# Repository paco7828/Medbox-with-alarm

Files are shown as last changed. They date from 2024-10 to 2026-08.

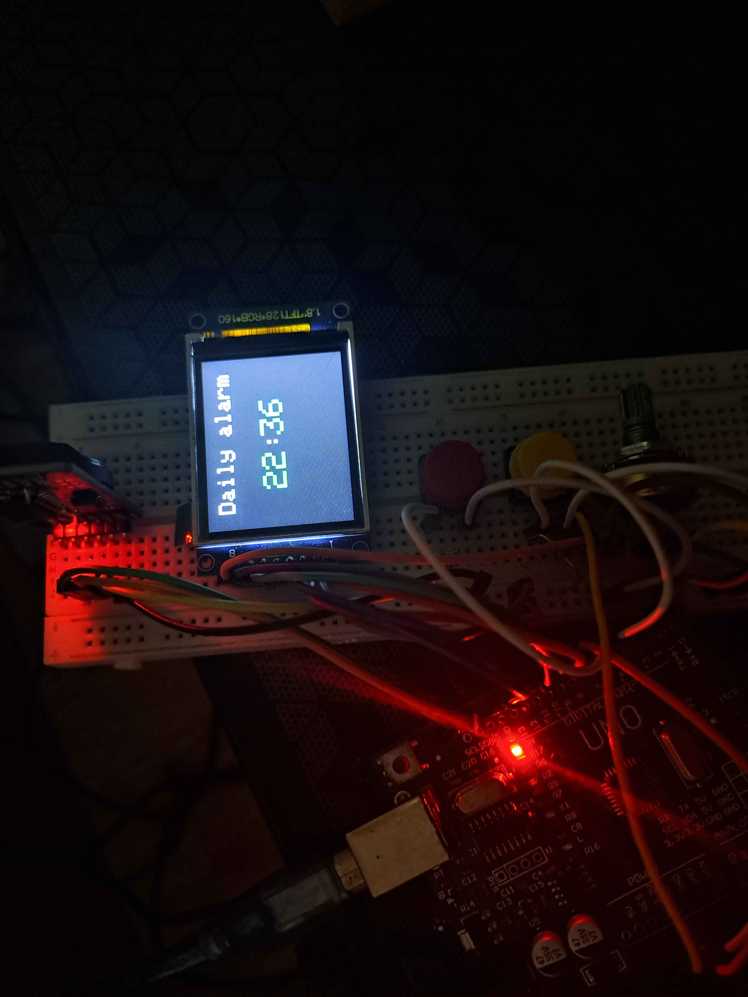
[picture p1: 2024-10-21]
models/proto-1.jpg

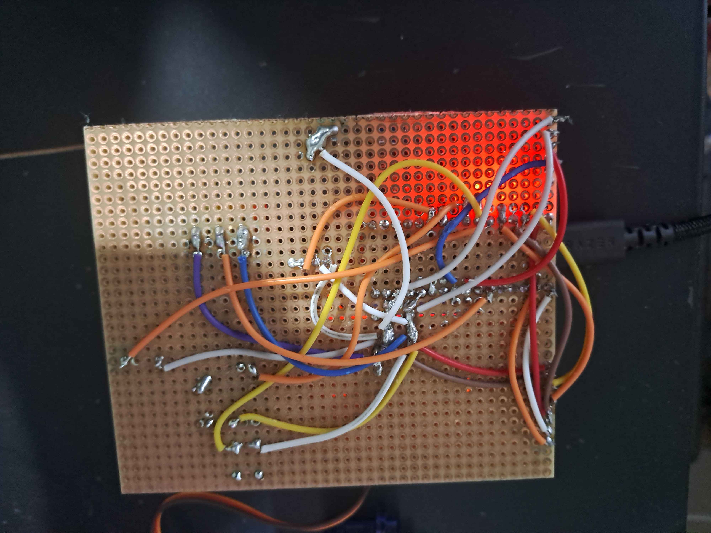
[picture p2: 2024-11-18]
models/v1-final-back.jpg

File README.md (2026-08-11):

# Timed Box

Battery-powered time-locked box driven by an ESP32-C3 Supermini. It functions as an interactive alarm clock that uses a servo motor to automatically open at a specific time. It utilizes deep sleep mode to preserve battery life when not actively in use.

## Features

- **Time-Triggered Lockbox:** Automatically triggers a servo to open the box when the programmed alarm goes off. The box automatically closes after 30 seconds.
- **Ultra-Low Power Mode:** Enters deep sleep after 60 seconds of inactivity. Automatically wakes up exactly when the alarm is due or via a manual button press.
- **1.8" TFT Display:** Shows real-time clock, date, day of the week, and current alarm status with optimized rendering.
- **Precision Timekeeping:** Uses a DS3231M RTC circuit to maintain accurate time independently of the MCU.
- **Audio Feedback:** Integrated buzzer plays alarm sequences and button interaction sounds.
- **Manual Override:** Long-pressing the main button allows you to manually open or close the box at any time without an alarm.
- **On-Device Configuration:** Two physical buttons to toggle the alarm state, configure the alarm time, and wake the device from sleep. Alarm times are saved in non-volatile memory.
- **Integrated Power Management:** Runs on a 3.7V LiPo battery. Includes a built-in USB-C charging circuit with battery protection and a boost converter for 5V components.

## Hardware Components

- **MCU:** ESP32-C3 SUPERMINI
- **RTC:** DS3231M
- **Display:** 1.8" TFT Screen (ST7735)
- **Actuator:** Servo Motor
- **Audio:** Active Buzzer
- **Power System:** 3.7V LiPo Battery, TP4056 Battery Charger / Protection module (with 8205A & DW01A), MT3608 Step-up Converter (3.7V -> 5V)
- **Inputs:** 2x Tactile Push Buttons, Power Switch

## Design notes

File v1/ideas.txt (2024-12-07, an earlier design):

Ideas:
-add different alarm sounds (functions) --> user can preview them and set an alarm sound
-attach servo to the circuit (small box which can be opened via servo) --> store medicine inside box
-attach water dispenser
	=> full medicine reminder kit (medicine alarm + box + water dispenser)
-add switch which acts as a screen on/off

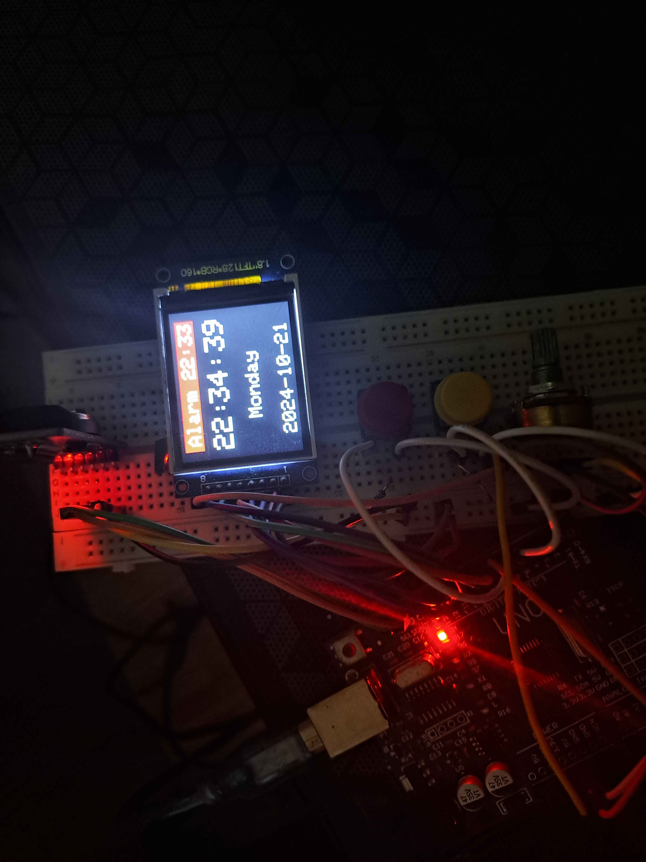
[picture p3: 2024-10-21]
models/proto-2.jpg

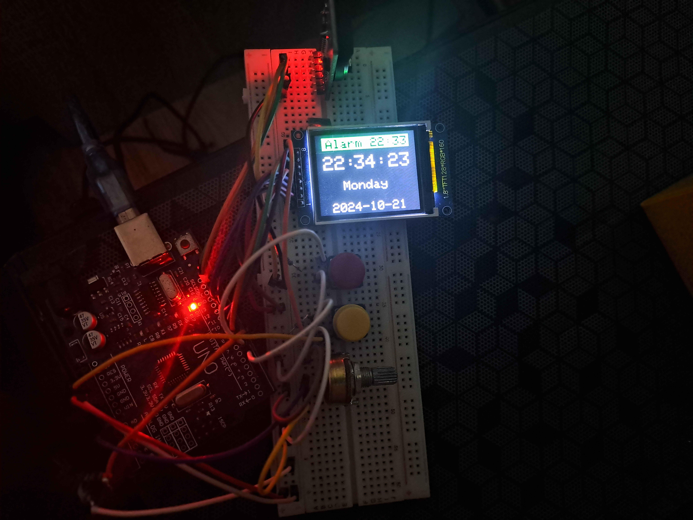
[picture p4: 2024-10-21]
models/proto-3.jpg

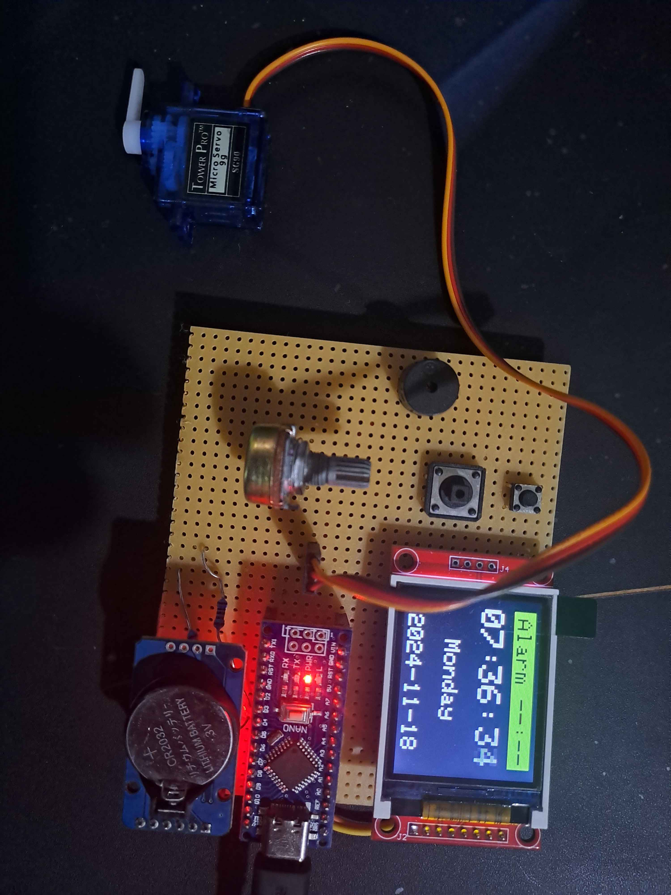
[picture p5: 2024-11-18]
models/v1-final-front.jpg

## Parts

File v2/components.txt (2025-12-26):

1x TYPE-C USB - https://www.hestore.hu/prod_10046971.html
2x 5.1k 0805 resistor - https://www.hestore.hu/prod_10001349.html
2x 1N5819 diode - https://www.hestore.hu/prod_10046229.html
1x Red LED - https://www.hestore.hu/prod_10043215.html
1x Green LED - https://www.hestore.hu/prod_10036384.html
3x 10uF 0805 capacitor - https://www.hestore.hu/prod_10032047.html
3x 1k 0805 resistor - https://www.hestore.hu/prod_10031299.html
1x TP4056 IC - https://www.hestore.hu/prod_10037291.html
1x 1.2k 0805 resistor - https://www.hestore.hu/prod_10001268.html
1x DW01 IC - https://www.hestore.hu/prod_10046612.html
1x 8205A IC - https://www.hestore.hu/prod_10045032.html
1x MT3608 IC - https://www.hestore.hu/prod_10048950.html
1x 22uH 0705 inductor - https://www.hestore.hu/prod_10046500.html
1x 7.5k 0805 resistor - https://www.hestore.hu/prod_10001197.html
1x B2B-XH-A - https://www.hestore.hu/prod_10041549.html
1x Buzzer - https://www.hestore.hu/prod_10044010.html
1x Power switch
1x B8B-XH-A - https://www.hestore.hu/prod_10041554.html
1x 1.8" TFT Display - https://www.hestore.hu/prod_10045986.html
1x 180° servo - https://www.hestore.hu/prod_10047934.html
1x MCU - https://www.hestore.hu/prod_10048018.html
2x 100nF 0805 capacitor - https://www.hestore.hu/prod_10001122.html
2x Button - https://www.hestore.hu/prod_10043772.html
1x DS3231M IC - https://www.aliexpress.com/item/1005008686698228.html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
2x 4.7k 0805 resistor - https://www.hestore.hu/prod_10001183.html
1x CR2032 Battery - https://www.hestore.hu/prod_10001070.html

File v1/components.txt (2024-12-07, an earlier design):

JC1216S18N (screen) --> https://www.hestore.hu/prod_10045986.html#
DS3231+AT24C32 RTCM (Real Time Clock module) --> https://www.hestore.hu/prod_10038042.html
LD-BZEN-1205 (buzzer) --> https://www.hestore.hu/prod_10040906.html
2x TACTS-12x12x7.3 (tact button) --> https://www.hestore.hu/prod_10042024.html
POM1615 LIN 10K B (potmeter) --> https://www.hestore.hu/prod_10027737.html
2x 10K 1% (pulldown resistor) --> https://www.hestore.hu/prod_10020541.html
AR-NANOCH-TYPE-C (microcontroller) --> https://www.hestore.hu/prod_10044468.html
MS/SG-90 servo (servo motor) --> https://www.hestore.hu/prod_10031188.html
TSM102A2 (toggle switch) --> https://www.hestore.hu/prod_10034537.html

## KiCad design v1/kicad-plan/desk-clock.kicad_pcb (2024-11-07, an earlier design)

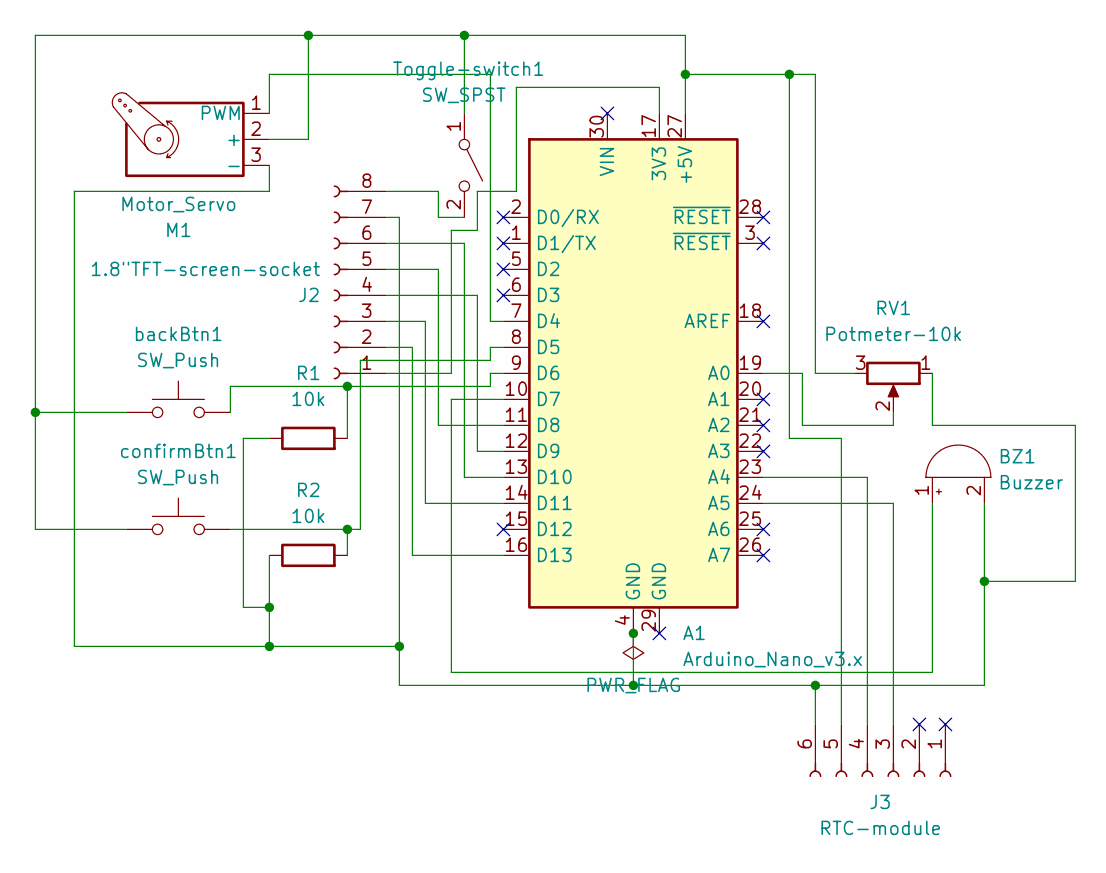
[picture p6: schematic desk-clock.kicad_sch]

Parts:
A1: Arduino_Nano_v3.x; Arduino_Nano
BZ1: Buzzer; Buzzer_TDK_PS1240P02BT_D12.2mm_H6.5mm
J2: 1.8"TFT-screen-socket; PinSocket_1x08_P2.54mm_Vertical
J3: RTC-module; PinSocket_1x06_P2.54mm_Vertical
M1: Motor_Servo; PinHeader_1x03_P2.54mm_Vertical
R1, R2: 10k; R_Axial_DIN0207_L6.3mm_D2.5mm_P10.16mm_Horizontal
RV1: Potmeter-10k; Potentiometer_Piher_PC-16_Single_Vertical
Toggle-switch1: SW_SPST; PinSocket_1x03_P2.54mm_Vertical
backBtn1: SW_Push; SW_Push_2P1T_Toggle_CK_PVA1xxH1xxxxxxV2
confirmBtn1: SW_Push; SW_Push_2P1T_Toggle_CK_PVA1xxH1xxxxxxV2

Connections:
unnamed: A1.17 (3V3), J2.1
unnamed: A1.27 (+5V), J3.5, M1.2 (+), RV1.3, Toggle-switch1.1 (A), backBtn1.1, confirmBtn1.1
unnamed: A1.19 (A0), RV1.2
unnamed: A1.23 (A4), J3.4
unnamed: A1.24 (A5), J3.3
unnamed: A1.7 (D4), M1.1 (PWM)
unnamed: A1.8 (D5), R2.2, confirmBtn1.2
unnamed: A1.9 (D6), R1.2, backBtn1.2
unnamed: A1.10 (D7), BZ1.1 (+)
unnamed: A1.11 (D8), J2.5
unnamed: A1.12 (D9), J2.4
unnamed: A1.13 (D10), J2.6
unnamed: A1.14 (D11), J2.3
unnamed: A1.16 (D13), J2.2
unnamed: A1.4 (GND), BZ1.2 (-), J2.7, J3.6, M1.3 (-), R1.1, R2.1, RV1.1
unnamed: J2.8, Toggle-switch1.2 (B)

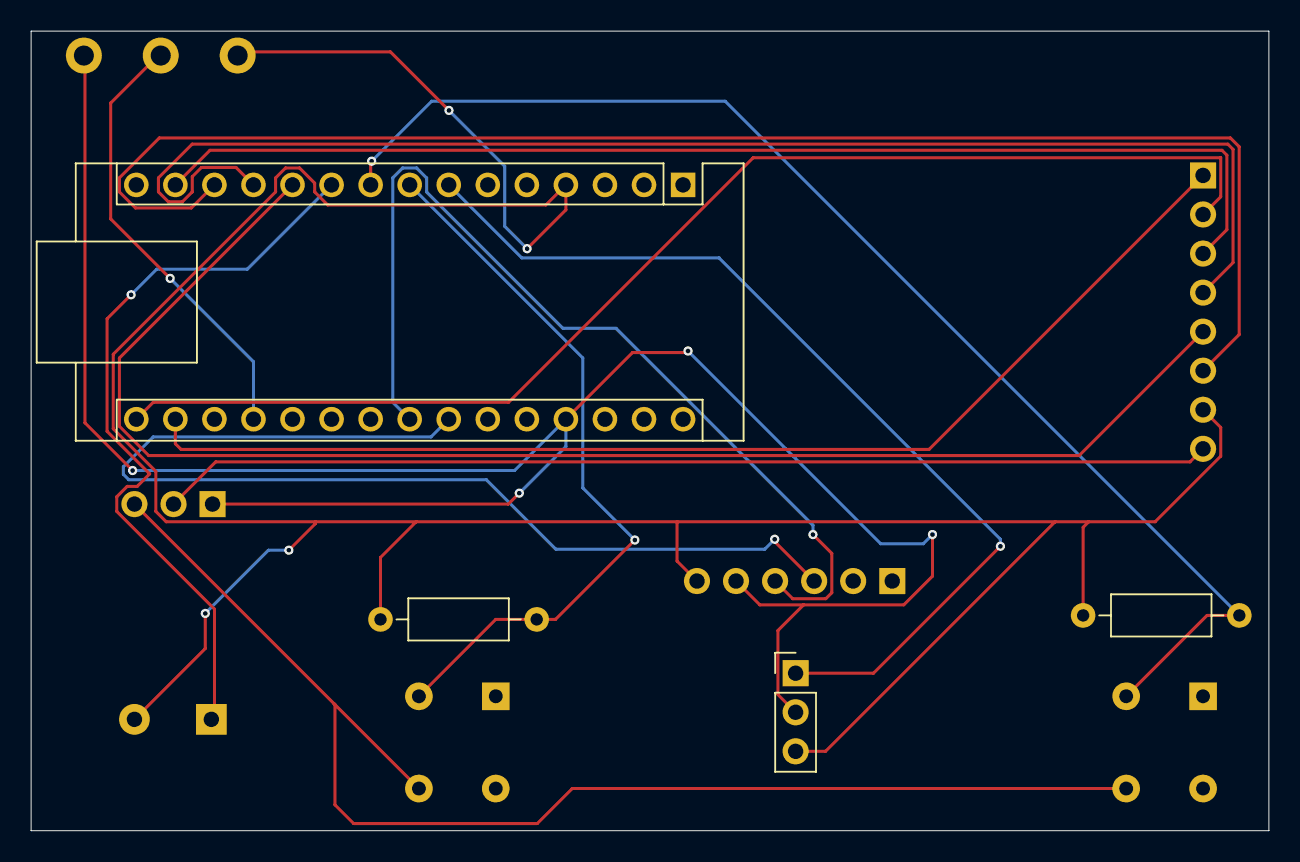
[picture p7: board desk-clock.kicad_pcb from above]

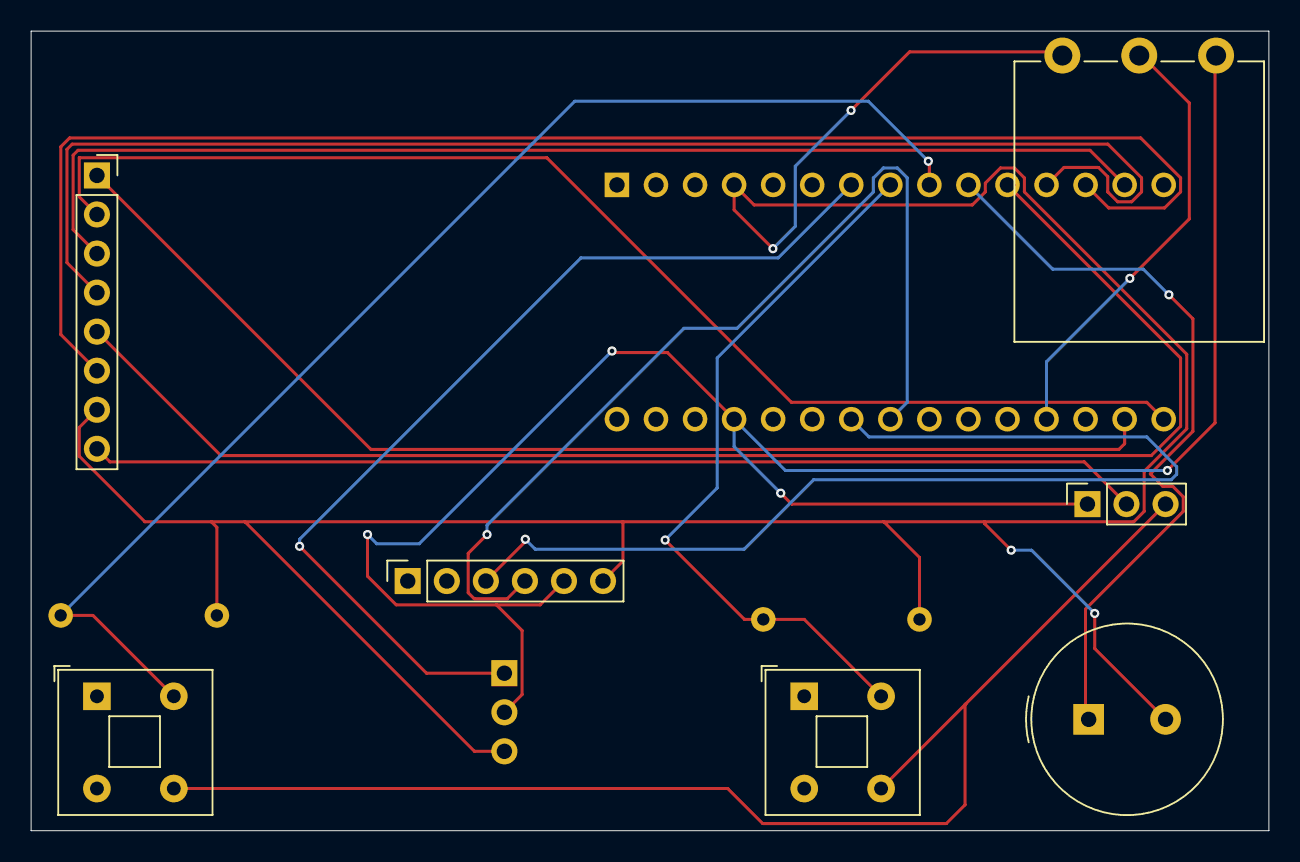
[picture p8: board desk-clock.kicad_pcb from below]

Board: 2 copper layers, 80.5 x 52.0 mm, 11 parts (7 on the bottom side), 16 nets.

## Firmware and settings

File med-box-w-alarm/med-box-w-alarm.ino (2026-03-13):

#include <Wire.h>
#include <RTClib.h>
#include <Adafruit_GFX.h>
#include <Adafruit_ST7735.h>
#include <Preferences.h>
#include <ESP32Servo.h>

// Pins
constexpr uint8_t TFT_CS = 9;
constexpr uint8_t TFT_DC = 5;
constexpr uint8_t TFT_RST = 8;
constexpr uint8_t TFT_MOSI = 4;
constexpr uint8_t TFT_SCK = 2;
constexpr uint8_t TFT_LED = 3;
constexpr uint8_t SERVO_PIN = 0;
constexpr uint8_t BTN1_PIN = 1;
constexpr uint8_t BTN2_PIN = 10;
constexpr uint8_t BUZZER_PIN = 20;
constexpr uint8_t RTC_SDA = 6;
constexpr uint8_t RTC_SCL = 7;

// Deep sleep
constexpr uint32_t AWAKE_TIME_MS = 60000;         // 1 minute (ms)
constexpr uint32_t MIN_SLEEP_TIME_US = 30000000;  // 30 seconds (µs)
unsigned long wakeTime = 0;

// Wakeup reason tracking - preserved across deep sleep
RTC_DATA_ATTR int lastAlarmHour = -1;
RTC_DATA_ATTR int lastAlarmMinute = -1;

// Instances
Servo boxServo;
RTC_DS3231 rtc;
Adafruit_ST7735 tft = Adafruit_ST7735(TFT_CS, TFT_DC, TFT_MOSI, TFT_SCK, TFT_RST);
Preferences preferences;

// RTC status
bool rtcFound = false;

// Helper variables
constexpr uint8_t BOX_OPEN_FOR = 30;  // seconds
bool alarmSet = true;
bool onMainScreen = true;
bool isHourSelected = true;
bool alarmActive = false;
bool boxOpen = false;
bool alarmStoppedForCurrentTime = false;
unsigned long boxOpenStartTime = 0;

// Button state variables
bool btn1LastReading = HIGH;
bool btn2LastReading = HIGH;
unsigned long btn1LastDebounceTime = 0;
unsigned long btn2LastDebounceTime = 0;
bool btn1State = HIGH;
bool btn2State = HIGH;
bool btn1LastStableState = HIGH;
bool btn2LastStableState = HIGH;

// BTN1 hold detection
const unsigned long HOLD_THRESHOLD_MS = 3000;  // 3 seconds to trigger hold
unsigned long btn1PressStartTime = 0;
bool btn1IsPhysicallyHeld = false;
bool btn1HoldActionFired = false;
bool manualBoxOpen = false;  // Box opened manually (separate from alarm)

// Button timing constants
const unsigned long doubleClickDelay = 400;
const unsigned long debounceDelay = 50;
unsigned long btn2FirstClick = 0;

// Alarm sound control
unsigned long lastBeepCycle = 0;
int beepState = 0;
bool alarmSoundActive = false;

// Alarm values
int alarmHourInt = 0;
int alarmMinuteInt = 0;

// Temporary alarm setting variables
int tempAlarmHour = 0;
int tempAlarmMinute = 0;

// Time display positioning and optimization
const int TIME_Y = 45;
const int TIME_SIZE = 3;

// Previous time values for optimization
int prevHourTens = -1;
int prevHourOnes = -1;
int prevMinTens = -1;
int prevMinOnes = -1;
int prevSecTens = -1;
int prevSecOnes = -1;

void setup() {
  wakeTime = millis();

  // Check wakeup reason FIRST
  esp_sleep_wakeup_cause_t wakeup_reason = esp_sleep_get_wakeup_cause();
  bool isGpioWakeup = (wakeup_reason == ESP_SLEEP_WAKEUP_GPIO);
  bool isFirstBoot = (wakeup_reason == ESP_SLEEP_WAKEUP_UNDEFINED);
  bool isTimerWakeup = (wakeup_reason == ESP_SLEEP_WAKEUP_TIMER);

  // Initialize Preferences
  preferences.begin("alarm-clock", false);

  // Load saved alarm values
  alarmHourInt = preferences.getInt("alarmHour", 0);
  alarmMinuteInt = preferences.getInt("alarmMin", 0);
  alarmSet = preferences.getBool("alarmSet", true);

  // Set up TFT backlight
  pinMode(TFT_LED, OUTPUT);
  digitalWrite(TFT_LED, HIGH);

  // Set up screen
  tft.initR(INITR_BLACKTAB);
  tft.fillScreen(ST77XX_BLACK);
  tft.setRotation(3);

  // Set up RTC with custom I2C pins
  Wire.begin(RTC_SDA, RTC_SCL);
  if (!rtc.begin()) {
    rtcFound = false;
  } else {
    rtcFound = true;

    // Check if time was already set manually
    bool timeWasSet = preferences.getBool("timeSet", false);

    if (!timeWasSet) {
      // MANUALLY SET THE TIME HERE ONLY ONCE!
      // Format: DateTime(year, month, day, hour, minute, second)
      rtc.adjust(DateTime(2025, 1, 30, 15, 33, 27));

      // Save flag so it doesn't reset again
      preferences.putBool("timeSet", true);
    }
  }

  // Set pins
  pinMode(BUZZER_PIN, OUTPUT);
  pinMode(BTN1_PIN, INPUT_PULLUP);
  pinMode(BTN2_PIN, INPUT_PULLUP);

  boxServo.attach(SERVO_PIN);

  // Check valid alarm values
  if (alarmHourInt > 23) alarmHourInt = 0;
  if (alarmMinuteInt > 59) alarmMinuteInt = 0;

  // Check if we should trigger alarm
  bool shouldTriggerAlarm = false;
  if (rtcFound && alarmSet) {
    DateTime now = rtc.now();

    // Only trigger if:
    // 1. We're at exact alarm time (hour and minute match)
    // 2. This alarm hasn't been triggered yet (check against last triggered hour/minute)
    if (now.hour() == alarmHourInt && now.minute() == alarmMinuteInt) {
      // Check if this is a new alarm (not already triggered)
      if (lastAlarmHour != alarmHourInt || lastAlarmMinute != alarmMinuteInt) {
        shouldTriggerAlarm = true;
        lastAlarmHour = alarmHourInt;
        lastAlarmMinute = alarmMinuteInt;
      }
    }

    showMainScreen(now);
  } else {
    showMainScreenNoRTC();
  }

  // Handle wakeup scenarios
  if (shouldTriggerAlarm) {
    // Alarm time - trigger alarm
    triggerAlarm();
    tone(BUZZER_PIN, 2000, 100);
    delay(150);
    tone(BUZZER_PIN, 2500, 100);
  } else if (isGpioWakeup) {
    // GPIO wakeup (button press) - just beep
    tone(BUZZER_PIN, 2000, 100);
    delay(150);
    tone(BUZZER_PIN, 2500, 100);
    boxServo.write(0);  // Ensure closed position
  } else if (isTimerWakeup) {
    // Timer wakeup means we're near alarm time - quick beep only
    tone(BUZZER_PIN, 1500, 50);
    boxServo.write(0);  // Ensure closed position
  } else {
    // First boot - full startup sequence with servo test
    tone(BUZZER_PIN, 2000, 100);
    delay(150);
    tone(BUZZER_PIN, 2500, 100);
  }
}

void loop() {
  if (millis() - wakeTime >= AWAKE_TIME_MS) {
    goToDeepSleep();
  }

  // Handle RTC time updates
  if (rtcFound && onMainScreen) {
    DateTime now = rtc.now();
    static int lastHour = -1;
    static int lastMinute = -1;
    static int lastSecond = -1;
    static String lastDateStr = "";

    String currentDateStr = String(now.year()) + "-" + getCorrectValue(String(now.month())) + "-" + getCorrectValue(String(now.day()));

    // Update date if changed
    if (currentDateStr != lastDateStr) {
      lastDateStr = currentDateStr;
      updateDateDisplay(now);
      updateDayDisplay(now);
    }

    // Get current values
    int currentHour = now.hour();
    int currentMinute = now.minute();
    int currentSecond = now.second();

    // OPTIMIZED: Only update changed digits
    if (currentHour != lastHour || currentMinute != lastMinute || currentSecond != lastSecond) {
      updateTimeDisplayOptimized(currentHour, currentMinute, currentSecond);
      lastHour = currentHour;
      lastMinute = currentMinute;
      lastSecond = currentSecond;
    }

    if (alarmSet) {
      // Reset the alarm if time has passed the alarm time
      if (currentHour != alarmHourInt || currentMinute != alarmMinuteInt) {
        alarmStoppedForCurrentTime = false;
      }

      // Reset last alarm tracking at midnight for next day's alarm
      if (currentHour == 0 && currentMinute == 0 && currentSecond == 0) {
        lastAlarmHour = -1;
        lastAlarmMinute = -1;
      }

      // Check if it's alarm time
      if (currentHour == alarmHourInt && currentMinute == alarmMinuteInt && currentSecond == 0 && !alarmStoppedForCurrentTime) {
        triggerAlarm();
        alarmStoppedForCurrentTime = true;
        lastAlarmHour = alarmHourInt;
        lastAlarmMinute = alarmMinuteInt;
      }

      // Stop alarm after 30 seconds if box closed
      if (boxOpen && millis() - boxOpenStartTime >= BOX_OPEN_FOR * 1000) {
        boxServo.write(0);  // Close the box
        boxOpen = false;
        alarmActive = false;
        alarmSoundActive = false;
        noTone(BUZZER_PIN);
      }
    }
  }

  // If alarm active, continue beeping
  if (alarmActive && alarmSoundActive) {
    handleAlarmSound();
  }

  if (onMainScreen) {
    handleMainScreenButtons();
  } else {
    handleAlarmSettingButtons();
  }
}

void goToDeepSleep() {
  // Don't sleep if the box is manually held open
  if (manualBoxOpen) {
    wakeTime = millis();  // Reset the sleep timer, keep running
    return;
  }

  digitalWrite(TFT_LED, LOW);
  tft.enableSleep(true);
  boxServo.detach();

  // GPIO wakeup on button press — always enabled
  esp_deep_sleep_enable_gpio_wakeup(1ULL << BTN1_PIN, ESP_GPIO_WAKEUP_GPIO_LOW);

  // Timer wakeup only when an alarm is scheduled
  if (alarmSet && rtcFound) {
    DateTime now = rtc.now();

    long currentTotalSec = (long)now.hour() * 3600 + now.minute() * 60 + now.second();
    long alarmTotalSec = (long)alarmHourInt * 3600 + alarmMinuteInt * 60;

    long secondsUntilAlarm = alarmTotalSec - currentTotalSec;
    if (secondsUntilAlarm <= 0) {
      secondsUntilAlarm += 24L * 3600;
    }

    uint64_t sleepTime = (uint64_t)secondsUntilAlarm * 1000000ULL;
    if (sleepTime < MIN_SLEEP_TIME_US) {
      sleepTime = MIN_SLEEP_TIME_US;
    }

    esp_sleep_enable_timer_wakeup(sleepTime);
  }

  esp_deep_sleep_start();
}

void handleMainScreenButtons() {
  // ── BTN1 hold detection (raw read, no debounce needed for timing) ──────
  bool btn1Raw = (digitalRead(BTN1_PIN) == LOW);

  if (btn1Raw && !btn1IsPhysicallyHeld) {
    // Button just went down — start timing
    btn1IsPhysicallyHeld = true;
    btn1PressStartTime = millis();
    btn1HoldActionFired = false;
  }

  if (btn1IsPhysicallyHeld && !btn1HoldActionFired) {
    if (millis() - btn1PressStartTime >= HOLD_THRESHOLD_MS) {
      // ── HOLD action: toggle box manually ────────────────────────────
      btn1HoldActionFired = true;
      wakeTime = millis();  // Prevent sleep immediately

      if (!manualBoxOpen) {
        // Open the box
        boxServo.write(180);
        manualBoxOpen = true;
        tone(BUZZER_PIN, 2500, 60);
        delay(80);
        tone(BUZZER_PIN, 3000, 60);
      } else {
        // Close the box
        boxServo.write(0);
        manualBoxOpen = false;
        tone(BUZZER_PIN, 3000, 60);
        delay(80);
        tone(BUZZER_PIN, 2500, 60);
      }
    }
  }

  if (!btn1Raw && btn1IsPhysicallyHeld) {
    // Button released
    bool wasShortPress = !btn1HoldActionFired;
    btn1IsPhysicallyHeld = false;

    if (wasShortPress) {
      // ── SHORT PRESS: stop alarm OR toggle alarm on/off ───────────────
      if (alarmActive) {
        boxServo.write(0);
        boxOpen = false;
        alarmActive = false;
        alarmSoundActive = false;
        alarmStoppedForCurrentTime = true;
        noTone(BUZZER_PIN);
        beepState = 0;
        tone(BUZZER_PIN, 1000, 200);
      } else {
        alarmSet = !alarmSet;
        preferences.putBool("alarmSet", alarmSet);
        updateAlarmIndicator();
        tone(BUZZER_PIN, 1500, 50);
      }
      wakeTime = millis();
    }
  }

  // ── BTN2: stop alarm OR enter alarm setting mode ──────────────────────
  if (alarmActive) {
    if (buttonPressed(BTN2_PIN, btn2LastReading, btn2LastDebounceTime, btn2State, btn2LastStableState)) {
      boxServo.write(0);
      boxOpen = false;
      alarmActive = false;
      alarmSoundActive = false;
      alarmStoppedForCurrentTime = true;
      noTone(BUZZER_PIN);
      beepState = 0;
      tone(BUZZER_PIN, 1000, 200);
      wakeTime = millis();
      return;
    }
  }

  if (buttonPressed(BTN2_PIN, btn2LastReading, btn2LastDebounceTime, btn2State, btn2LastStableState)) {
    showDailyAlarm();
    tone(BUZZER_PIN, 2000, 50);
    wakeTime = millis();
  }
}

void handleAlarmSettingButtons() {
  static bool waitingForDoubleClick = false;
  static unsigned long singleClickTime = 0;

  // BTN1: Increment hour or minute
  if (buttonPressed(BTN1_PIN, btn1LastReading, btn1LastDebounceTime, btn1State, btn1LastStableState)) {
    btn2FirstClick = 0;
    waitingForDoubleClick = false;

    if (isHourSelected) {
      tempAlarmHour = (tempAlarmHour + 1) % 24;
      updateAlarmHour(getCorrectValue(String(tempAlarmHour)));
    } else {
      tempAlarmMinute = (tempAlarmMinute + 1) % 60;
      updateAlarmMinute(getCorrectValue(String(tempAlarmMinute)));
    }
    tone(BUZZER_PIN, 1800, 30);
    wakeTime = millis();
  }

  // BTN2: Decrement or double-click to confirm
  if (buttonPressed(BTN2_PIN, btn2LastReading, btn2LastDebounceTime, btn2State, btn2LastStableState)) {
    unsigned long currentTime = millis();

    if (waitingForDoubleClick && (currentTime - singleClickTime < doubleClickDelay)) {
      // Double-click detected
      waitingForDoubleClick = false;

      if (isHourSelected) {
        // Confirm hour, move to minute
        preferences.putInt("alarmHour", tempAlarmHour);
        alarmHourInt = tempAlarmHour;
        isHourSelected = false;

        tft.setCursor(35, 50);
        tft.setTextSize(3);
        tft.setTextColor(ST77XX_WHITE);
        tft.fillRect(34, 49, 40, 23, ST77XX_BLACK);
        tft.print(getCorrectValue(String(tempAlarmHour)));

        tft.setCursor(85, 50);
        tft.setTextSize(3);
        tft.setTextColor(ST77XX_GREEN);
        tft.fillRect(81, 49, 41, 23, ST77XX_BLACK);
        tft.print(getCorrectValue(String(tempAlarmMinute)));

        tone(BUZZER_PIN, 2500, 100);
        delay(100);
        tone(BUZZER_PIN, 3000, 100);
      } else {
        // Confirm minute, save and return to main screen
        preferences.putInt("alarmMin", tempAlarmMinute);
        alarmMinuteInt = tempAlarmMinute;
        onMainScreen = true;
        isHourSelected = true;

        // Reset last alarm tracking since we set a new alarm
        lastAlarmHour = -1;
        lastAlarmMinute = -1;

        if (rtcFound) {
          showMainScreen(rtc.now());
        } else {
          showMainScreenNoRTC();
        }

        tone(BUZZER_PIN, 2500, 100);
        delay(100);
        tone(BUZZER_PIN, 3000, 100);
        delay(100);
        tone(BUZZER_PIN, 3500, 100);
      }
    } else {
      // Wait for double-click
      waitingForDoubleClick = true;
      singleClickTime = currentTime;
    }
    wakeTime = millis();
  }

  // Check if single-click timeout expired
  if (waitingForDoubleClick && (millis() - singleClickTime >= doubleClickDelay)) {
    waitingForDoubleClick = false;
    if (isHourSelected) {
      tempAlarmHour = (tempAlarmHour - 1 + 24) % 24;
      updateAlarmHour(getCorrectValue(String(tempAlarmHour)));
    } else {
      tempAlarmMinute = (tempAlarmMinute - 1 + 60) % 60;
      updateAlarmMinute(getCorrectValue(String(tempAlarmMinute)));
    }
    tone(BUZZER_PIN, 1600, 30);
  }
}

// Function to handle button press with debouncing
bool buttonPressed(int pin, bool &lastReading, unsigned long &lastDebounceTime, bool &buttonState, bool &lastStableState) {
  bool reading = digitalRead(pin);
  bool pressed = false;

  // If the reading changed reset debounce timer
  if (reading != lastReading) {
    lastDebounceTime = millis();
  }

  // If enough time has passed, accept the reading as stable
  if ((millis() - lastDebounceTime) > debounceDelay) {
    // If the stable state changed
    if (reading != buttonState) {
      buttonState = reading;

      // Only register a press on the falling edge (HIGH to LOW)
      if (buttonState == LOW && lastStableState == HIGH) {
        pressed = true;
      }
      lastStableState = buttonState;
    }
  }

  lastReading = reading;
  return pressed;
}

// OPTIMIZED: Only redraw changed digits
void updateTimeDisplayOptimized(int hour, int minute, int second) {
  int hourTens = hour / 10;
  int hourOnes = hour % 10;
  int minTens = minute / 10;
  int minOnes = minute % 10;
  int secTens = second / 10;
  int secOnes = second % 10;

  tft.setTextSize(TIME_SIZE);
  tft.setTextColor(ST77XX_WHITE);

  // Get actual character dimensions
  int16_t x1, y1;
  uint16_t charW, charH;
  tft.getTextBounds("0", 0, 0, &x1, &y1, &charW, &charH);

  uint16_t colonW;
  tft.getTextBounds(":", 0, 0, &x1, &y1, &colonW, &charH);

  // Calculate total width and starting position
  String fullTime = getCorrectValue(String(hour)) + ":" + getCorrectValue(String(minute)) + ":" + getCorrectValue(String(second));
  uint16_t totalW, totalH;
  tft.getTextBounds(fullTime, 0, 0, &x1, &y1, &totalW, &totalH);
  int baseX = (tft.width() - totalW) / 2;

  // Calculate positions for each element
  int pos = baseX;

  // Hour tens
  if (hourTens != prevHourTens) {
    tft.fillRect(pos - 1, TIME_Y - 1, charW + 2, charH + 2, ST77XX_BLACK);
    tft.setCursor(pos, TIME_Y);
    tft.print(hourTens);
    prevHourTens = hourTens;
  }
  pos += charW;

  // Hour ones
  if (hourOnes != prevHourOnes) {
    tft.fillRect(pos - 1, TIME_Y - 1, charW + 2, charH + 2, ST77XX_BLACK);
    tft.setCursor(pos, TIME_Y);
    tft.print(hourOnes);
    prevHourOnes = hourOnes;
  }
  pos += charW;

  // Colon 1
  tft.setCursor(pos, TIME_Y);
  tft.print(":");
  pos += colonW;

  // Minute tens
  if (minTens != prevMinTens) {
    tft.fillRect(pos - 1, TIME_Y - 1, charW + 2, charH + 2, ST77XX_BLACK);
    tft.setCursor(pos, TIME_Y);
    tft.print(minTens);
    prevMinTens = minTens;
  }
  pos += charW;

  // Minute ones
  if (minOnes != prevMinOnes) {
    tft.fillRect(pos - 1, TIME_Y - 1, charW + 2, charH + 2, ST77XX_BLACK);
    tft.setCursor(pos, TIME_Y);
    tft.print(minOnes);
    prevMinOnes = minOnes;
  }
  pos += charW;

  // Colon 2
  tft.setCursor(pos, TIME_Y);
  tft.print(":");
  pos += colonW;

  // Second tens
  if (secTens != prevSecTens) {
    tft.fillRect(pos - 1, TIME_Y - 1, charW + 2, charH + 2, ST77XX_BLACK);
    tft.setCursor(pos, TIME_Y);
    tft.print(secTens);
    prevSecTens = secTens;
  }
  pos += charW;

  // Second ones
  if (secOnes != prevSecOnes) {
    tft.fillRect(pos - 1, TIME_Y - 1, charW + 2, charH + 2, ST77XX_BLACK);
    tft.setCursor(pos, TIME_Y);
    tft.print(secOnes);
    prevSecOnes = secOnes;
  }
}

void updateDateDisplay(DateTime now) {
  String dateStr = String(now.year()) + "-" + getCorrectValue(String(now.month())) + "-" + getCorrectValue(String(now.day()));
  tft.fillRect(0, 80, tft.width(), 20, ST77XX_BLACK);
  drawCenteredText(dateStr, 80, 2, ST77XX_WHITE);
}

void updateDayDisplay(DateTime now) {
  String dayStr = getDayName(now.dayOfTheWeek());
  tft.fillRect(0, 105, tft.width(), 20, ST77XX_BLACK);
  drawCenteredText(dayStr, 105, 2, ST77XX_CYAN);
}

void updateAlarmIndicator() {
  tft.fillRect(0, 5, tft.width(), 25, ST77XX_BLACK);
  tft.fillRect(0, 5, tft.width(), 25, alarmSet ? ST77XX_GREEN : ST77XX_RED);
  String alarmText = "Alarm " + getCorrectValue(String(alarmHourInt)) + ":" + getCorrectValue(String(alarmMinuteInt));
  drawCenteredText(alarmText, 8, 2, alarmSet ? ST77XX_BLACK : ST77XX_WHITE);
}

void showMainScreen(DateTime now) {
  onMainScreen = true;
  tft.fillScreen(ST77XX_BLACK);
  updateAlarmIndicator();

  // Reset previous values to force full redraw
  prevHourTens = -1;
  prevHourOnes = -1;
  prevMinTens = -1;
  prevMinOnes = -1;
  prevSecTens = -1;
  prevSecOnes = -1;

  // Clear the entire time display area to prevent overlapping
  tft.fillRect(0, TIME_Y - 2, tft.width(), 30, ST77XX_BLACK);

  updateTimeDisplayOptimized(now.hour(), now.minute(), now.second());
  updateDateDisplay(now);
  updateDayDisplay(now);
}

void showMainScreenNoRTC() {
  onMainScreen = true;
  tft.fillScreen(ST77XX_BLACK);
  updateAlarmIndicator();

  // Reset previous values
  prevHourTens = -1;
  prevHourOnes = -1;
  prevMinTens = -1;
  prevMinOnes = -1;
  prevSecTens = -1;
  prevSecOnes = -1;

  // Clear the entire time display area to prevent overlapping
  tft.fillRect(0, TIME_Y - 2, tft.width(), 30, ST77XX_BLACK);

  updateTimeDisplayOptimized(0, 0, 0);
  drawCenteredText("YYYY-MM-DD", 80, 2, ST77XX_WHITE);
  drawCenteredText("Unknown", 105, 2, ST77XX_CYAN);
}

String getCorrectValue(String timePart) {
  return timePart.length() < 2 ? "0" + timePart : timePart;
}

void handleAlarmSound() {
  unsigned long now = millis();

  switch (beepState) {
    case 0:  // First beep
      if (now - lastBeepCycle >= 200) {
        tone(BUZZER_PIN, 3700);
        lastBeepCycle = now;
        beepState = 1;
      }
      break;

    case 1:  // Pause after first beep
      if (now - lastBeepCycle >= 200) {
        noTone(BUZZER_PIN);
        lastBeepCycle = now;
        beepState = 2;
      }
      break;

    case 2:  // Second beep
      if (now - lastBeepCycle >= 200) {
        tone(BUZZER_PIN, 3700);
        lastBeepCycle = now;
        beepState = 3;
      }
      break;

    case 3:  // Pause after second beep
      if (now - lastBeepCycle >= 200) {
        noTone(BUZZER_PIN);
        lastBeepCycle = now;
        beepState = 4;
      }
      break;

    case 4:  // Third beep
      if (now - lastBeepCycle >= 200) {
        tone(BUZZER_PIN, 3700);
        lastBeepCycle = now;
        beepState = 5;
      }
      break;

    case 5:  // Pause after third beep
      if (now - lastBeepCycle >= 200) {
        noTone(BUZZER_PIN);
        lastBeepCycle = now;
        beepState = 6;
      }
      break;

    case 6:  // 5 second silence
      noTone(BUZZER_PIN);
      if (now - lastBeepCycle >= 5000) {
        lastBeepCycle = now;
        beepState = 0;  // Restart cycle
      }
      break;
  }
}

void triggerAlarm() {
  alarmActive = true;
  alarmSoundActive = true;
  beepState = 0;
  lastBeepCycle = millis();

  if (!boxOpen) {
    boxServo.write(180);
    boxOpen = true;
    boxOpenStartTime = millis();
  }
}
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

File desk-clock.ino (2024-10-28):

#include <Wire.h>
#include <RTClib.h>
#include <Adafruit_GFX.h>
#include <Adafruit_ST7735.h>
#include <EEPROM.h>
#include <Servo.h> // Include servo library

// Define TFT pins
#define TFT_CS 10
#define TFT_DC 9
#define TFT_RST 8


// Initialize servo
Servo boxServo;
// Initialize RTC
RTC_DS3231 rtc;

// Initialize TFT screen
Adafruit_ST7735 tft = Adafruit_ST7735(TFT_CS, TFT_DC, TFT_RST);

// Helper variables
bool alarmSet = true;
String days[] = { "Sunday", "Monday", "Tuesday", "Wednesday", "Thursday", "Friday", "Saturday" };
bool onMainScreen;
bool isHourSelected;

// Variables for potmeter values
int potValue;
int lastPotValue;

// Initialize additional pins
int alarmPin = 7;
int backBtn = 6;
int confirmBtn = 5;
int potPin = A0;

// Boolean variables for button states
bool backBtnState;
bool confirmBtnState;

// Get alarm values from EEPROM
int alarmHourInt = EEPROM.read(0);
int alarmMinuteInt = EEPROM.read(1);

// New variable to track if alarm has been stopped for the current alarm time
bool alarmStoppedForCurrentTime = false;

void setup() {
  // Set up screen
  tft.initR(INITR_BLACKTAB);
  tft.fillScreen(ST7735_BLACK);
  tft.setRotation(1);

  // Set up RTC
  if (!rtc.begin()) {
    tft.setCursor(30, 55);
    tft.setTextSize(1);
    tft.print("Couldn't find RTC");
    while (1)
      ;
  }

  if (rtc.lostPower()) {
    tft.setCursor(30, 45);
    tft.setTextSize(1);
    tft.print("RTC lost power,");
    tft.setCursor(30, 55);
    tft.print("setting the time!");
    rtc.adjust(DateTime(F(__DATE__), F(__TIME__)));
  }

  // Load main screen by default
  showMainScreen(rtc.now());

  // Set pins
  pinMode(alarmPin, OUTPUT);
  pinMode(backBtn, INPUT);
  pinMode(confirmBtn, INPUT);
  boxServo.attach(4);
}

void loop() {
  DateTime now = rtc.now();
  static int lastHour = -1;
  static int lastMinute = -1;
  static int lastSecond = -1;
  static String lastDay = "";
  static String lastYMD = "";

  // Get current values
  int currentHour = now.hour();
  int currentMinute = now.minute();
  int currentSecond = now.second();
  String currentDay = getCurrentDay(now);
  String currentYMD = getCurrentYMD(now);

  if (onMainScreen) {
    if (alarmSet) {
      // Reset alarmStoppedForCurrentTime when it's no longer alarm time
      if (currentHour != alarmHourInt || currentMinute != alarmMinuteInt) {
        alarmStoppedForCurrentTime = false;
      }

      // Start alarm at specified time if it hasn't been stopped
      if (currentHour == alarmHourInt && currentMinute == alarmMinuteInt && currentSecond <= 30 && !alarmStoppedForCurrentTime) {
        triggerAlarm();
        boxServo.write(180); // Open med-box
        // When back button is pressed turn off alarm
        bool backBtnCurrentState = debounceBtn(backBtn, backBtnState);
        if (backBtnCurrentState == HIGH && backBtnState == LOW) {
          alarmStoppedForCurrentTime = true;
          backBtnState = HIGH;
        } else if (backBtnCurrentState == LOW && backBtnState == HIGH) {
          backBtnState = LOW;
        }
      }
    }
    // Update only changed values
    if (currentSecond != lastSecond) {
      lastSecond = currentSecond;
      updateCurrentSecond(currentSecond);
    }
    if (currentMinute != lastMinute) {
      lastMinute = currentMinute;
      updateCurrentMinute(currentMinute);
    }
    if (currentHour != lastHour) {
      lastHour = currentHour;
      updateCurrentHour(currentHour);
    }
    if (currentDay != lastDay) {
      lastDay = currentDay;
      updateCurrentDay(currentDay);
    }
    if (currentYMD != lastYMD) {
      lastYMD = currentYMD;
      updateCurrentYMD(currentYMD);
    }

    // When backBtn is pressed
    bool backBtnCurrentState = debounceBtn(backBtn, backBtnState);
    if (backBtnCurrentState == HIGH && backBtnState == LOW) {
      if (!onMainScreen) {
        showMainScreen(now);
      } else {
        // Update the alarm indicator on the screen
        alarmSet = !alarmSet;
        updateAlarmIndicator();
      }
      backBtnState = HIGH;
    } else if (backBtnCurrentState == LOW && backBtnState == HIGH) {
      backBtnState = LOW;
    }

    // When confirmBtn is pressed
    bool confirmBtnCurrentState = debounceBtn(confirmBtn, confirmBtnState);
    if (confirmBtnCurrentState == HIGH && confirmBtnState == LOW) {
      // Show daily alarm screen
      showDailyAlarm();
      confirmBtnState = HIGH;
    } else if (confirmBtnCurrentState == LOW && confirmBtnState == HIGH) {
      confirmBtnState = LOW;
    }
  }
}

// Functions to update each values on the main screen
void updateCurrentHour(int hour) {
  tft.setCursor(10, 35);
  tft.setTextSize(3);
  tft.setTextColor(ST7735_WHITE);
  tft.fillRect(10, 35, 50, 40, ST7735_BLACK);
  tft.print(getCorrectValue(String(hour)) + ":");
}

void updateCurrentMinute(int minute) {
  tft.setCursor(60, 35);
  tft.setTextSize(3);
  tft.setTextColor(ST7735_WHITE);
  tft.fillRect(60, 35, 50, 40, ST7735_BLACK);
  tft.print(getCorrectValue(String(minute)) + ":");
}

void updateCurrentSecond(int second) {
  tft.setCursor(115, 35);
  tft.setTextSize(3);
  tft.setTextColor(ST7735_WHITE);
  tft.fillRect(115, 35, 50, 40, ST7735_BLACK);
  tft.print(getCorrectValue(String(second)));
}

void updateCurrentDay(String day) {
  tft.setCursor(40, 75);
  tft.setTextSize(2);
  tft.setTextColor(ST7735_WHITE);
  tft.fillRect(40, 75, 100, 20, ST7735_BLACK);
  tft.print(day);
}

void updateCurrentYMD(String ymd) {
  tft.setCursor(20, 110);
  tft.setTextSize(2);
  tft.setTextColor(ST7735_WHITE);
  tft.fillRect(20, 110, 120, 20, ST7735_BLACK);
  tft.print(ymd);
}

void updateAlarmIndicator() {
  tft.fillRect(10, 5, 140, 20, alarmSet ? ST7735_GREEN : ST7735_RED);
  tft.setCursor(16, 8);
  tft.setTextSize(2);
  tft.setTextColor(alarmSet ? ST7735_BLACK : ST7735_WHITE);
  tft.print("Alarm " + (alarmHourInt != 255 ? getCorrectValue(String(alarmHourInt)) : "--") + ":" + (alarmMinuteInt != 255 ? getCorrectValue(String(alarmMinuteInt)) : "--"));
}

void showMainScreen(DateTime now) {
  onMainScreen = true;
  // Reset main screen and update values
  tft.fillScreen(ST7735_BLACK);
  updateAlarmIndicator();
  updateCurrentHour(now.hour());
  updateCurrentMinute(now.minute());
  updateCurrentSecond(now.second());
  updateCurrentDay(getCurrentDay(now));
  updateCurrentYMD(getCurrentYMD(now));
}

// Function to return the corresponding value
String getCurrentYMD(DateTime now) {
  return String(now.year()) + "-" + String(now.month()) + "-" + String(now.day());
}

String getCorrectValue(String timePart) {
  return timePart.length() < 2 ? "0" + timePart : timePart;
}

String getCurrentDay(DateTime now) {
  return days[now.dayOfTheWeek()];
}

// Alarm sound function
void triggerAlarm() {
  tone(alarmPin, 2000, 100);
  delay(500);
}

// Function for button debouncing
bool debounceBtn(int btn, bool& lastState) {
  bool currentState = digitalRead(btn);
  if (currentState != lastState) {
    delay(200);
    currentState = digitalRead(btn);
  }
  return currentState;
}
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

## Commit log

2024-10-20 Update desk-clock.ino - Main screen layout print
2024-10-22 Added wiring's visual representation
2024-10-28 Added new wiring plan with servo
2024-10-29 Update components.txt with screen's on/off switch
2024-10-29 Added new wiring - extended with screen's switch
2024-10-29 Update components.txt with a new toggle switch
2024-11-03 Added RTC module's wiring
2024-11-07 Added new kicad plan
    [desk-clock.kicad_pcb, desk-clock.kicad_sch]
2024-11-18 Added models folder to store prototypes and real life models
2024-12-07 Sorted the files, start of compact, smaller build begins.
    [desk-clock.kicad_pcb, desk-clock.kicad_sch]
2024-12-31 Modified code so alarm doesn't interrupt time display + new alarm
    [med-box-w-alarm.ino]
2025-12-23 Added deep sleep functionality for power saving feature.
2025-12-26 Added V2 PCB.
2025-12-27 Changed battery connector polarity on V2 PCB.
2026-01-01 Fixed switched up TFT connections on V2 PCB.
2026-01-03 Added correct medbox v2 pcb.
2026-01-03 Moved V2 PCB to the V2 folder.
2026-01-21 Fixed code with correctly centered time displaying.
    [med-box-w-alarm.ino]
2026-02-02 Fixed code opening from deep sleep.
    [med-box-w-alarm.ino]
2026-02-11 Removed automated timer.
2026-02-22 Removed servo test sequence from startup.
2026-03-03 Updated code so it calculates wakeup time better and uses less battery.
2026-03-13 Added box-opening logic with button holding.
